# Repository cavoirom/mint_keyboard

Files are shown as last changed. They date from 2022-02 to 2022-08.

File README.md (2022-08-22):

# Mint Keyboard

Mint is an attempt to build 4x12 ortholinear keyboard with ***Weact STM32F411CEU6 Black Pill***. This repository include PCB design, plate design that anyone can build a Mint for themselves.

## Bill of materials

| Name | Quantities | Ref | Description |
|---|---|-----|---|
| Weact STM32F411CEU6 Black Pill | 1 | | Keyboard controller |
| 1N4148 Diode | 47 | | |
| Kailh Hotswap Socket | 44 | | |
| Mill-Max sockets 0305 | 6 | | 3 sockets above the controller could not use Kailh socket. |

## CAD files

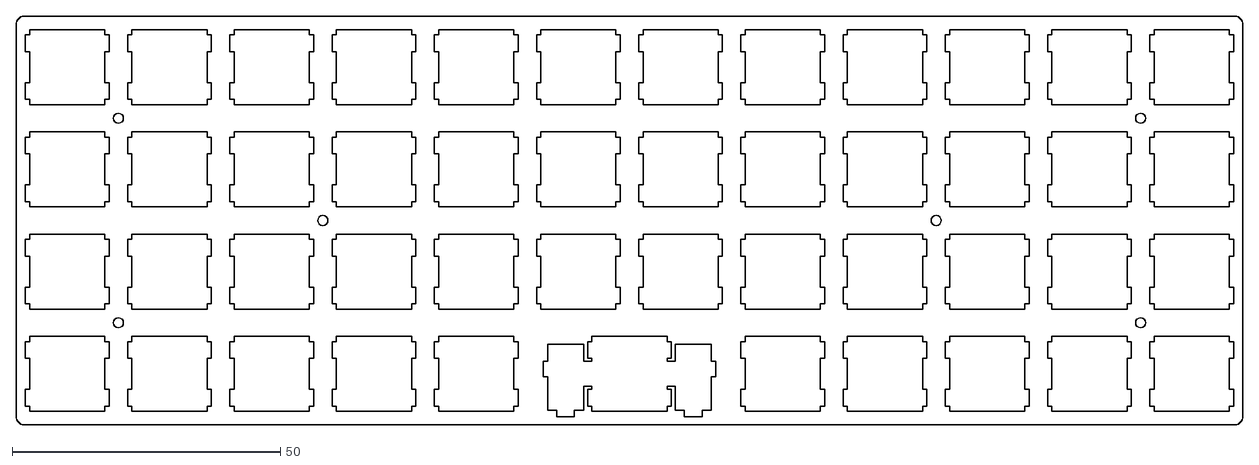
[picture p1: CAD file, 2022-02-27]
plate/mint_plate_top.dxf
228.6 x 76.2

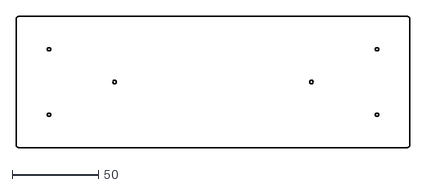
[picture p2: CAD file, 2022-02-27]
plate/mint_plate_bottom.dxf
228.6 x 76.2

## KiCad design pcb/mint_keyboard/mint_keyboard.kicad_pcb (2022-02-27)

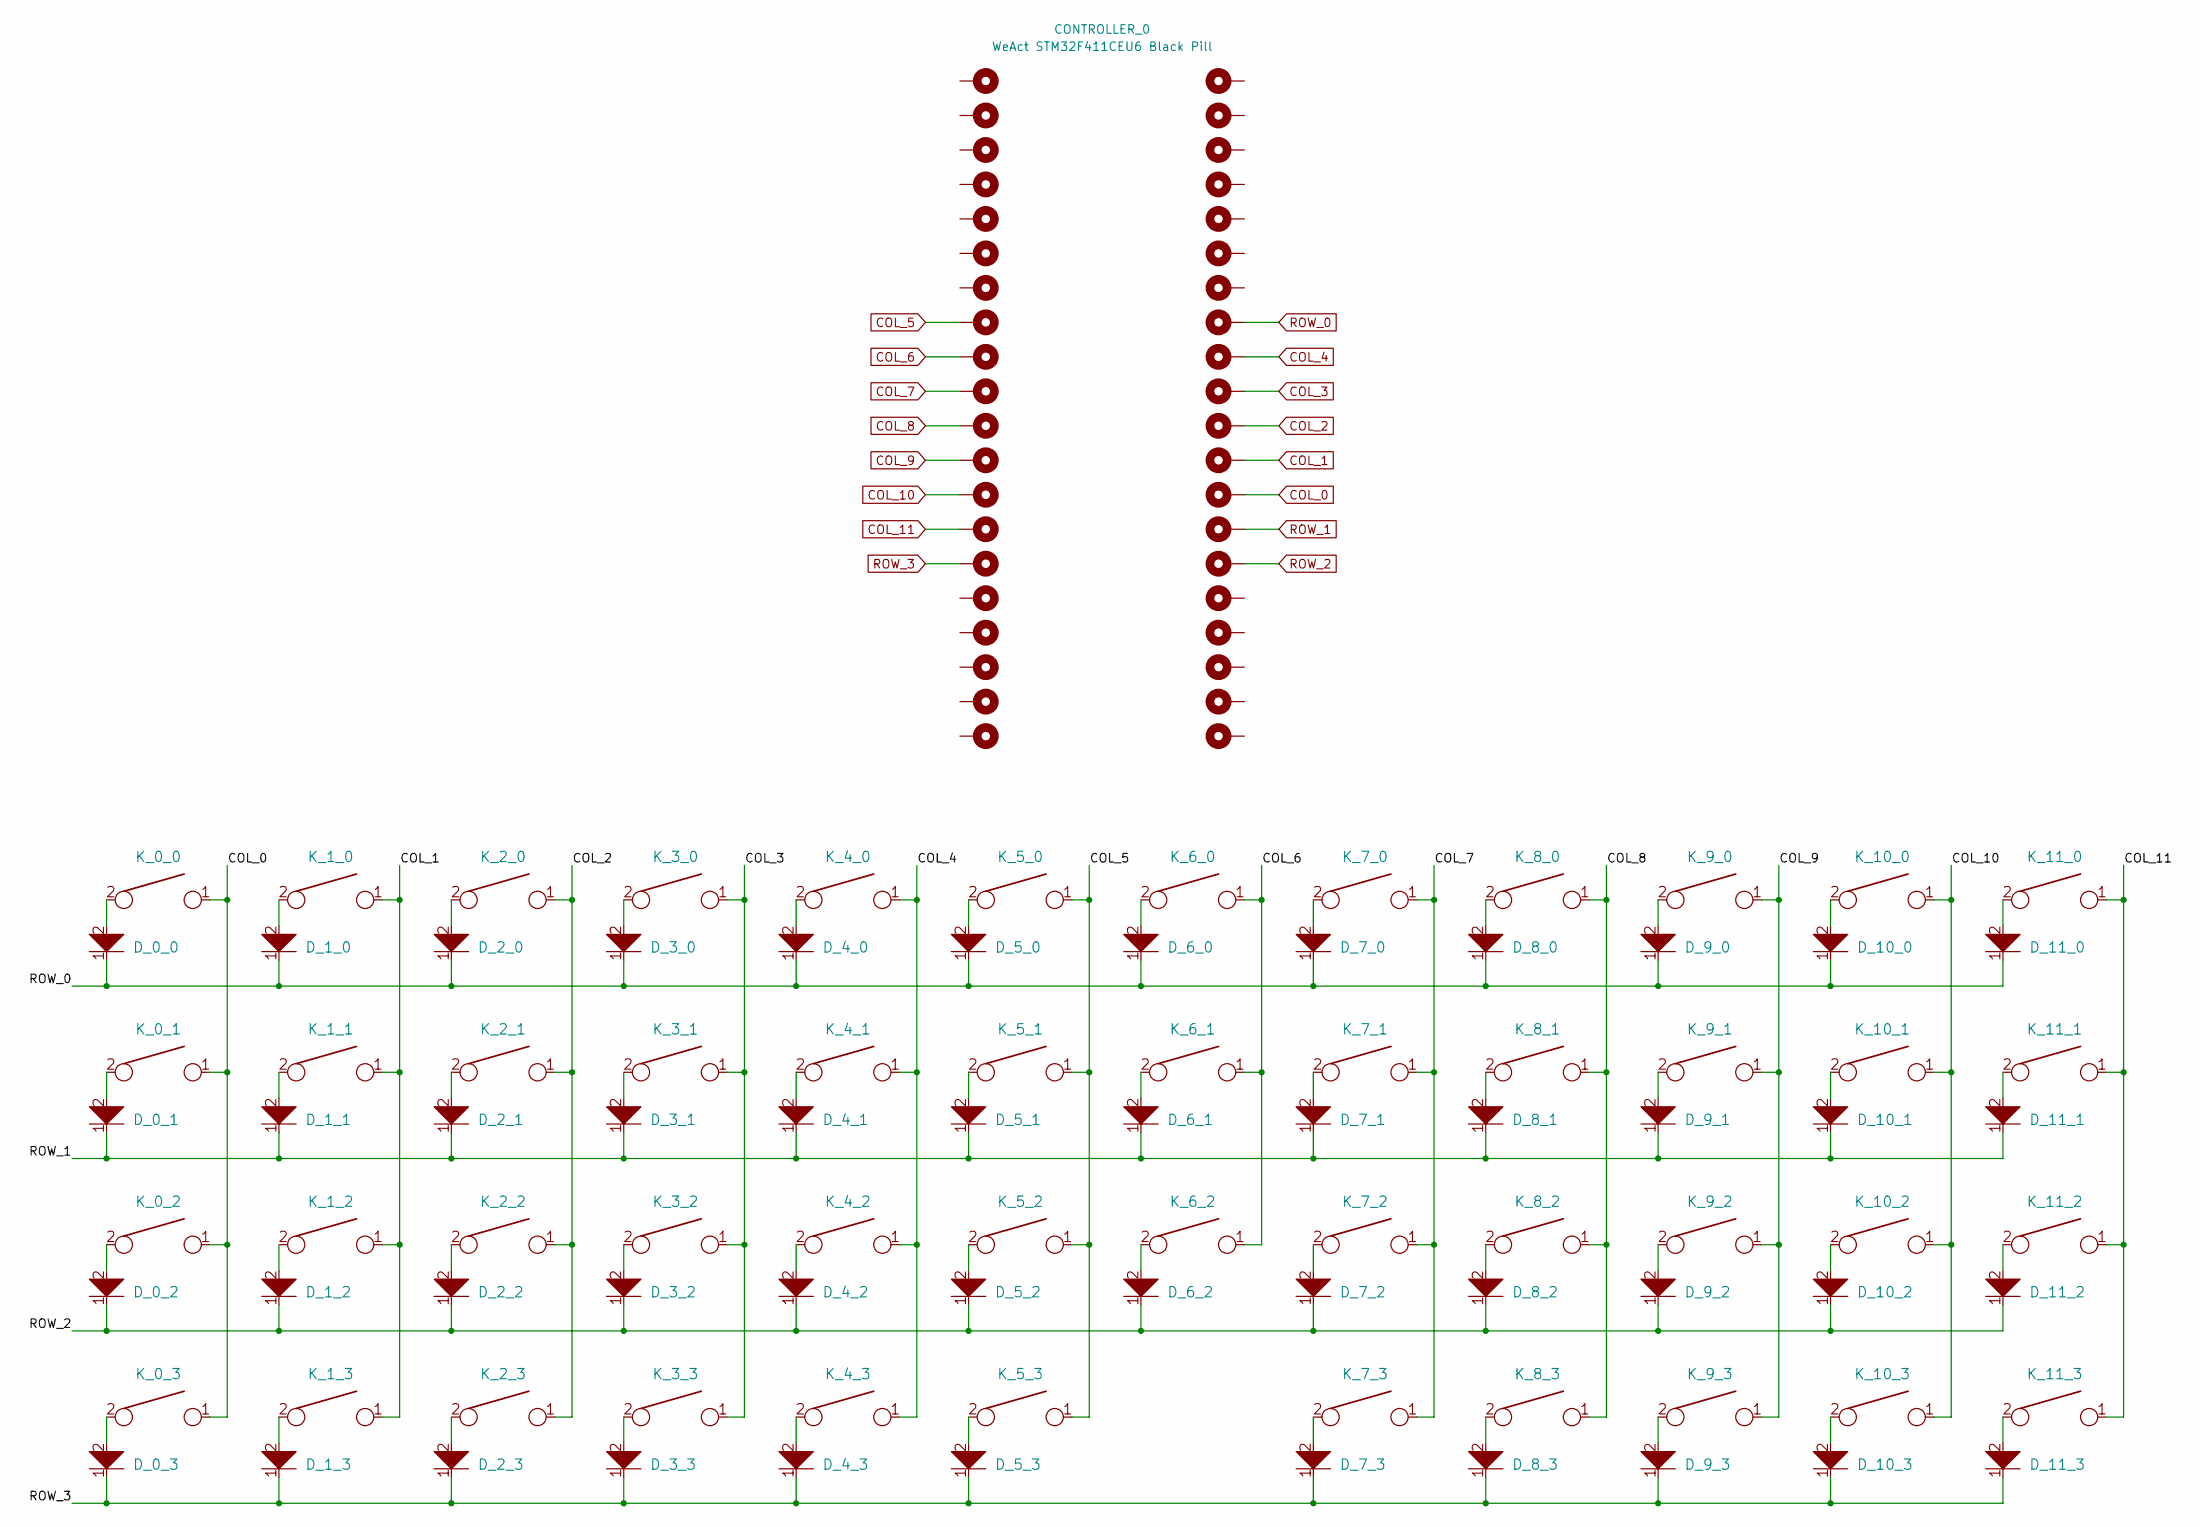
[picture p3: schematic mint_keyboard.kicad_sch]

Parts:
CONTROLLER_0: WeAct STM32F411CEU6 Black Pill; WeAct_STM32F411CEU6_Black_Pill_v3
D_0_0, D_0_1, D_0_2, D_0_3, D_1_0, D_1_1, D_1_2, D_1_3, D_2_0, D_2_1, D_2_2, D_2_3, D_3_0, D_3_1, D_3_2, D_3_3, D_4_0, D_4_1, D_4_2, D_4_3, D_5_0, D_5_1, D_5_2, D_5_3, D_6_0, D_6_1, D_6_2, D_7_0, D_7_1, D_7_2, D_7_3, D_8_0, D_8_1, D_8_2, D_8_3, D_9_0, D_9_1, D_9_2, D_9_3, D_10_0, D_10_1, D_10_2, D_10_3, D_11_0, D_11_1, D_11_2, D_11_3: D; D_DO-35_SOD27_P7.62mm_Horizontal
K_0_0: TAB; Kailh_socket_MX_padding
K_0_1, K_0_2, K_0_3, K_1_1, K_1_2, K_1_3, K_2_1, K_2_2, K_2_3, K_3_1, K_3_2, K_3_3, K_4_3, K_5_1, K_5_2, K_5_3, K_6_1, K_6_2, K_7_1, K_7_2, K_7_3, K_8_1, K_8_2, K_8_3, K_9_1, K_9_2, K_9_3, K_10_1, K_10_2, K_10_3, K_11_1, K_11_2, K_11_3: KEYSW; Kailh_socket_MX_padding
K_1_0: QUOTE; Kailh_socket_MX_padding
K_2_0: COMMA; Kailh_socket_MX_padding
K_3_0: PERIOD; Kailh_socket_MX_padding
K_4_0: P; SW_MX_padding
K_4_1, K_4_2: KEYSW; SW_MX_padding
K_5_0: Y; Kailh_socket_MX_padding
K_6_0: F; Kailh_socket_MX_padding
K_7_0: G; Kailh_socket_MX_padding
K_8_0: C; Kailh_socket_MX_padding
K_9_0: R; Kailh_socket_MX_padding
K_10_0: L; Kailh_socket_MX_padding
K_11_0: BACKSPACE; Kailh_socket_MX_padding

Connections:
COL_0: CONTROLLER_0.33 (A2), K_0_0.1, K_0_1.1, K_0_2.1, K_0_3.1
COL_1: CONTROLLER_0.32 (A3), K_1_0.1, K_1_1.1, K_1_2.1, K_1_3.1
COL_2: CONTROLLER_0.31 (A4), K_2_0.1, K_2_1.1, K_2_2.1, K_2_3.1
COL_3: CONTROLLER_0.30 (A5), K_3_0.1, K_3_1.1, K_3_2.1, K_3_3.1
COL_4: CONTROLLER_0.29 (A6), K_4_0.1, K_4_1.1, K_4_2.1, K_4_3.1
COL_5: CONTROLLER_0.8 (A11), K_5_0.1, K_5_1.1, K_5_2.1, K_5_3.1
COL_6: CONTROLLER_0.9 (A12), K_6_0.1, K_6_1.1, K_6_2.1
COL_7: CONTROLLER_0.10 (A15), K_7_0.1, K_7_1.1, K_7_2.1, K_7_3.1
COL_8: CONTROLLER_0.11 (B3), K_8_0.1, K_8_1.1, K_8_2.1, K_8_3.1
COL_9: CONTROLLER_0.12 (B4), K_9_0.1, K_9_1.1, K_9_2.1, K_9_3.1
COL_10: CONTROLLER_0.13 (B5), K_10_0.1, K_10_1.1, K_10_2.1, K_10_3.1
COL_11: CONTROLLER_0.14 (B6), K_11_0.1, K_11_1.1, K_11_2.1, K_11_3.1
unnamed: D_0_0.2, K_0_0.2
unnamed: D_0_1.2, K_0_1.2
unnamed: D_0_2.2, K_0_2.2
unnamed: D_0_3.2, K_0_3.2
unnamed: D_1_0.2, K_1_0.2
unnamed: D_1_1.2, K_1_1.2
unnamed: D_1_2.2, K_1_2.2
unnamed: D_1_3.2, K_1_3.2
unnamed: D_2_0.2, K_2_0.2
unnamed: D_2_1.2, K_2_1.2
unnamed: D_2_2.2, K_2_2.2
unnamed: D_2_3.2, K_2_3.2
unnamed: D_3_0.2, K_3_0.2
unnamed: D_3_1.2, K_3_1.2
unnamed: D_3_2.2, K_3_2.2
unnamed: D_3_3.2, K_3_3.2
unnamed: D_4_0.2, K_4_0.2
unnamed: D_4_1.2, K_4_1.2
unnamed: D_4_2.2, K_4_2.2
unnamed: D_4_3.2, K_4_3.2
unnamed: D_5_0.2, K_5_0.2
unnamed: D_5_1.2, K_5_1.2
unnamed: D_5_2.2, K_5_2.2
unnamed: D_5_3.2, K_5_3.2
unnamed: D_6_0.2, K_6_0.2
unnamed: D_6_1.2, K_6_1.2
unnamed: D_6_2.2, K_6_2.2
unnamed: D_7_0.2, K_7_0.2
unnamed: D_7_1.2, K_7_1.2
unnamed: D_7_2.2, K_7_2.2
unnamed: D_7_3.2, K_7_3.2
unnamed: D_8_0.2, K_8_0.2
unnamed: D_8_1.2, K_8_1.2
unnamed: D_8_2.2, K_8_2.2
unnamed: D_8_3.2, K_8_3.2
unnamed: D_9_0.2, K_9_0.2
unnamed: D_9_1.2, K_9_1.2
unnamed: D_9_2.2, K_9_2.2
unnamed: D_9_3.2, K_9_3.2
unnamed: D_10_0.2, K_10_0.2
unnamed: D_10_1.2, K_10_1.2
unnamed: D_10_2.2, K_10_2.2
unnamed: D_10_3.2, K_10_3.2
unnamed: D_11_0.2, K_11_0.2
unnamed: D_11_1.2, K_11_1.2
unnamed: D_11_2.2, K_11_2.2
unnamed: D_11_3.2, K_11_3.2
ROW_0: CONTROLLER_0.28 (A7), D_0_0.1, D_1_0.1, D_2_0.1, D_3_0.1, D_4_0.1, D_5_0.1, D_6_0.1, D_7_0.1, D_8_0.1, D_9_0.1, D_10_0.1, D_11_0.1
ROW_1: CONTROLLER_0.34 (A1), D_0_1.1, D_1_1.1, D_2_1.1, D_3_1.1, D_4_1.1, D_5_1.1, D_6_1.1, D_7_1.1, D_8_1.1, D_9_1.1, D_10_1.1, D_11_1.1
ROW_2: CONTROLLER_0.35 (A0), D_0_2.1, D_1_2.1, D_2_2.1, D_3_2.1, D_4_2.1, D_5_2.1, D_6_2.1, D_7_2.1, D_8_2.1, D_9_2.1, D_10_2.1, D_11_2.1
ROW_3: CONTROLLER_0.15 (B7), D_0_3.1, D_1_3.1, D_2_3.1, D_3_3.1, D_4_3.1, D_5_3.1, D_7_3.1, D_8_3.1, D_9_3.1, D_10_3.1, D_11_3.1

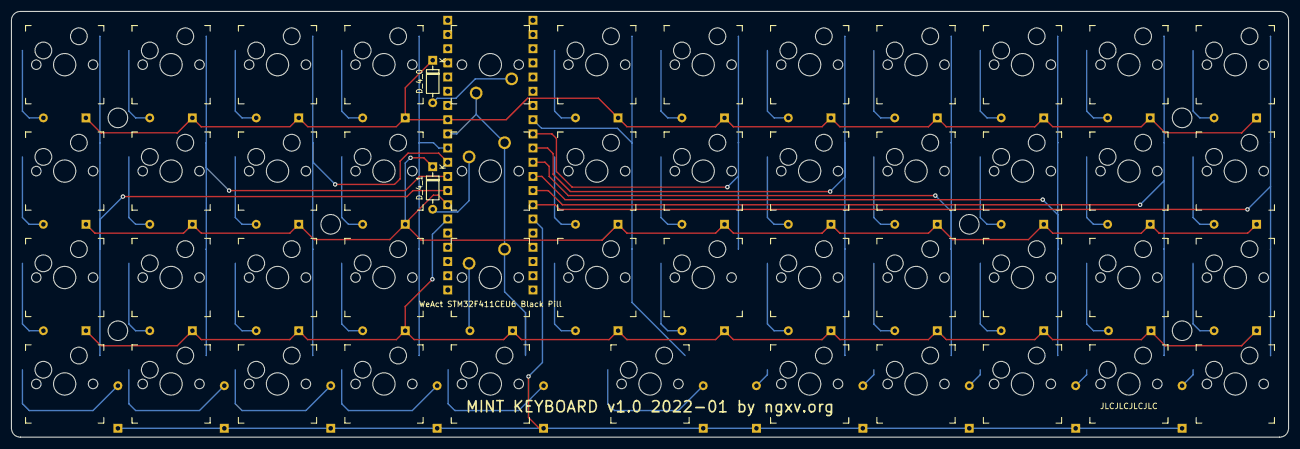
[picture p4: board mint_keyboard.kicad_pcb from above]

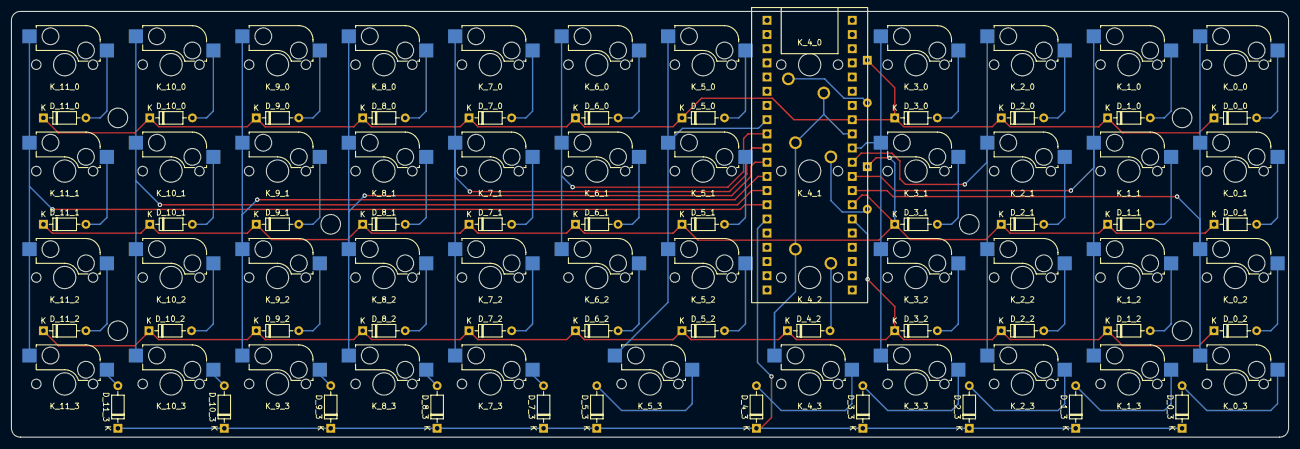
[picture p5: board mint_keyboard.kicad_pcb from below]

Board: 2 copper layers, 228.6 x 76.2 mm, 101 parts (46 on the bottom side), 63 nets.

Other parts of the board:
PLATE_HOLE_1, PLATE_HOLE_2, PLATE_HOLE_3, PLATE_HOLE_4, PLATE_HOLE_5, PLATE_HOLE_6: MountingHole_3.5mm

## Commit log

2022-02-27 Added Mint Keyboard v1.0 PCB.
    [mint_keyboard.kicad_pcb, mint_keyboard.kicad_sch]
2022-02-27 Added Mint top/bottom plate.
    [mint_plate_bottom.dxf, mint_plate_top.dxf]
2022-08-22 Added bill of materials to README.md
2022-08-22 Update bill of materials table with 1N4148 Diode, Kailh Hotswap Socket, Mill-Max sockets 0305.
